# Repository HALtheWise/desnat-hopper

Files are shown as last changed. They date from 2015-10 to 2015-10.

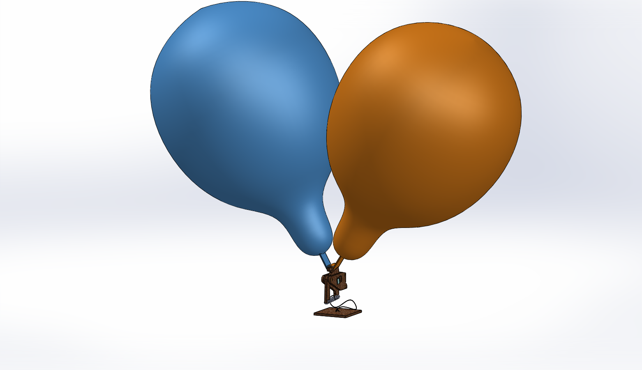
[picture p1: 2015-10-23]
Final cut files/Full blimp aslaunched 1.PNG

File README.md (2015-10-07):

# desnat-hopper
"Hopper" (blimp) for Design Nature

All first-year students at Olin get to take a class called Design Nature, 
in which we are challenged to create a biologically-inspired hopping creation from a very limited list of parts.

Project description (2015): http://web.archive.org/web/20151007031634/http://design.olin.edu/courses/dn/project/p1-requirements

Parts list (2015): http://web.archive.org/web/20151007031404/http://design.olin.edu/courses/dn/project/p1-prototyping-kit

Taking inspiration from nature, I noticed that the insects that reach the greatest heights and distances
do so by flying. A particulary enlightening example are spiders, some species of which can spin silk
balloons to loft themselves thousands of feet in the air and travel many miles.

Utilizing the presence of tap water in the list, and the general allowance on using tools to alter the given materials,
I have decided to split the H2O to make hydrogen, then use that to lift a blimp hundreds of feet in the air.

This is still a work in progress, and success is far from certain. This repository contains all the CAD 
and many of the calculations necessary to move forward.

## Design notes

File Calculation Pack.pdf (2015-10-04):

Eric Miller | Hoppers: Feasibility calculation pack | October 2, 2015

# Section 1: Buoyancy

## Starting point

- Dry mass of hopper is required to equal 50g or more, for this purpose hitting exactly 50g should be possible.
- Density of air at sea level is
- Density of 100% pure hydrogen is
- Density of 90% H2

, 10% O2

is
Assuming 90% effectiveness at separation during electrolysis:

= (http://www.wolframalpha.com/input/)

## Balloon volume

The party balloons we are given have a nominal diameter of 12”. Assuming spheres, their combined volume is thus:

=
Were this the case,

= 33.24 g

which is well shy of the needed lift.

Fortunately: inflating, measuring and photographing a balloon, then tracing in SolidWorks reveals:

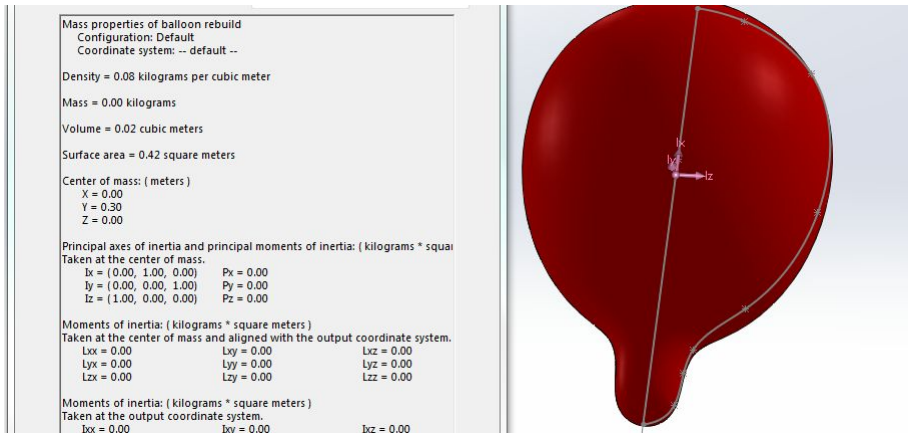
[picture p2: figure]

Volume of one balloon = 24607840.12 mm^3 = 0.024607840 m^3 Buoyancy of 2 balloons = 0.024607840 m^3 * 2 * 1.121 kilograms per cubic meter (http://www.wolframalpha.com/input/?i=0.024607840+m%5E3+*+2+*+1.121+kilograms+per+cubic+meter) = 55.17 grams

Note that it is probably possible to get significantly more volume inside by further overinflating if needed.

# Section 2: Aerodynamics

The obvious question is: how much vertical velocity does 5.17g of lift allow for? Note that this equates to about .05N of force.

## Solidworks flow simulation results (velocity = 0.5 m/s):

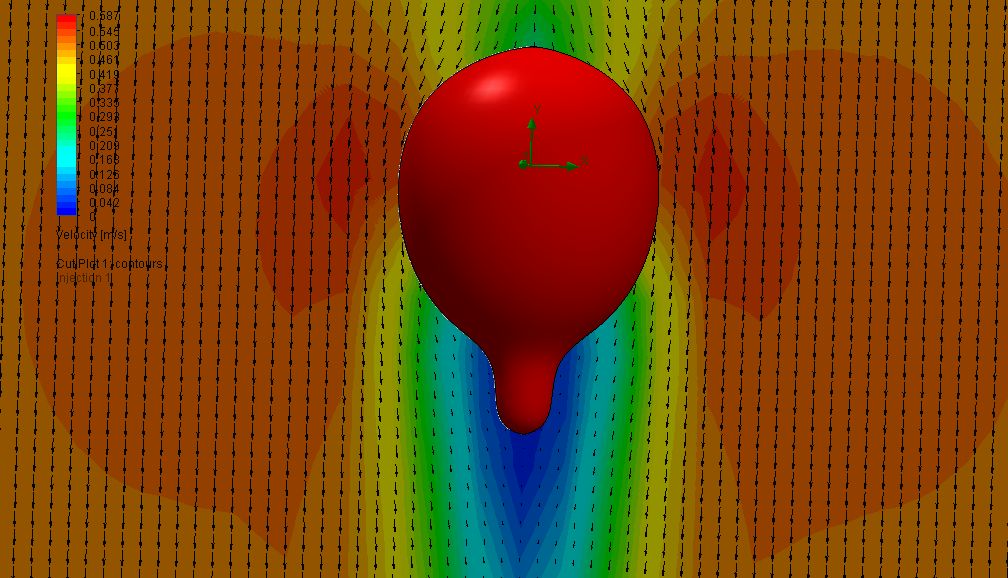
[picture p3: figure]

## Calculations

Because aerodynamic drag is roughly proportional to the square of velocity:

# Section 3: Ascent rate

As derived previously:

Thus

Because the target height of the device is 300ft, estimated travel time is

# Section 4: Comparison to simulation

The simulation data, pasted below, showed an estimated max height of 300 feet after 65 seconds of flight. The calculations here do not take into account gradual acceleration, and record more significant figures of accuracy, but are fundamentally based on the same aerodynamic calculations, and record a very similar height of 300 feet in 73.1 seconds. Stored mechanical energy is not particularly relevant to the calculations here, but there are other significant sources of error that make experimental testing necessary to figure out the correct timing to reach the height goal as accurately as possible. Firstly, the surface properties of the balloons aerodynamically are not necessarily modeled correctly, nor is the angle of attack modelled. Secondly the gondola itself has significant effect on the flight that is not properly accounted for in simulations or calculation. Overall, the damper effect used in the simulation matches expected results reasonably well.

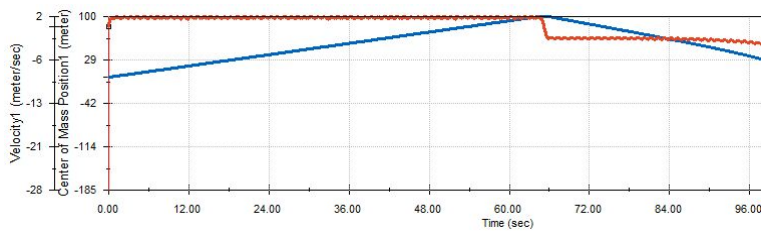
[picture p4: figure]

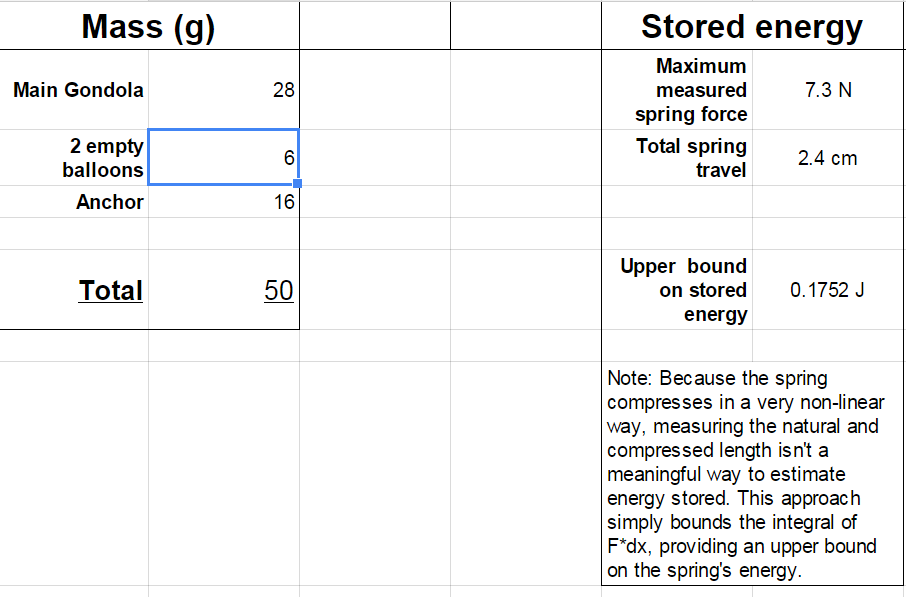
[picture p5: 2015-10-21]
Qualification calculations.PNG

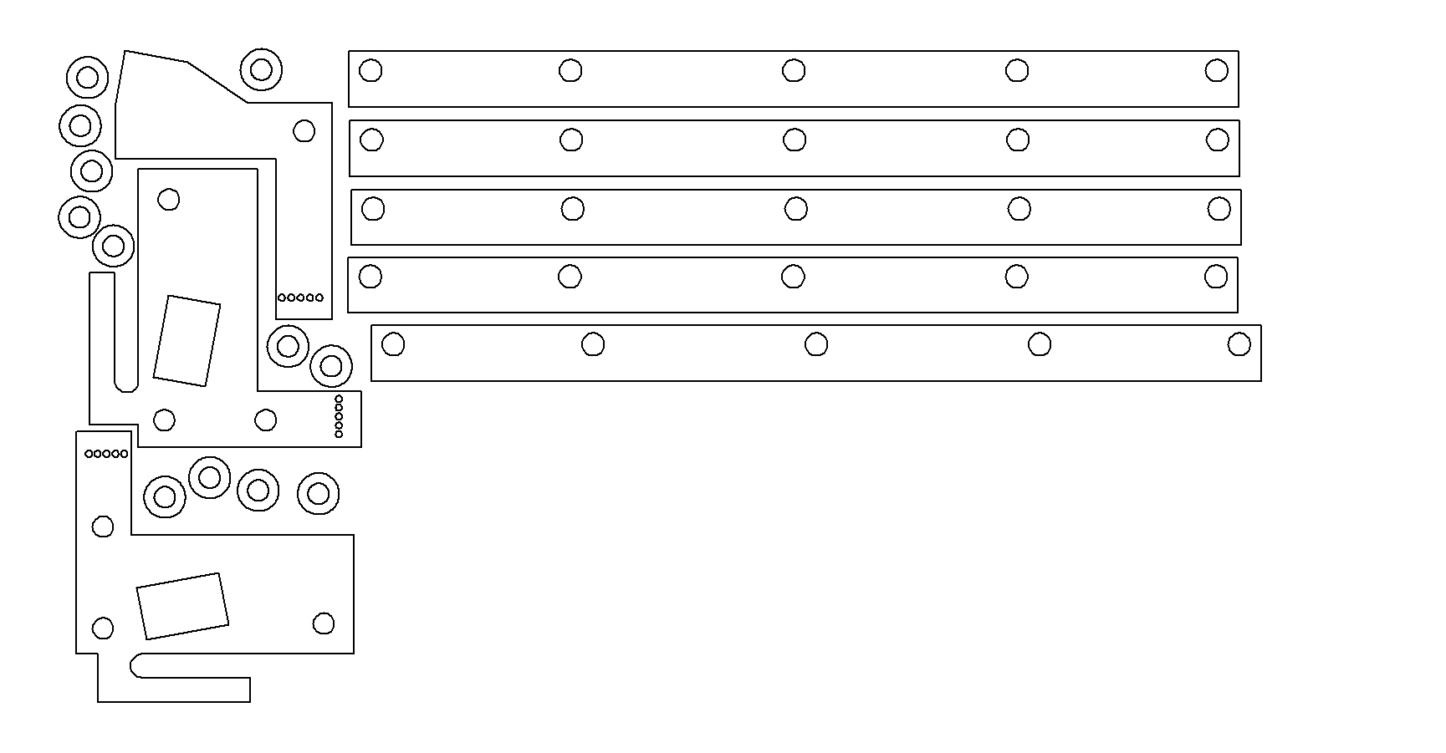
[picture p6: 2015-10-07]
Final cut files/Cutting files/EricMiller_cut_file.JPG

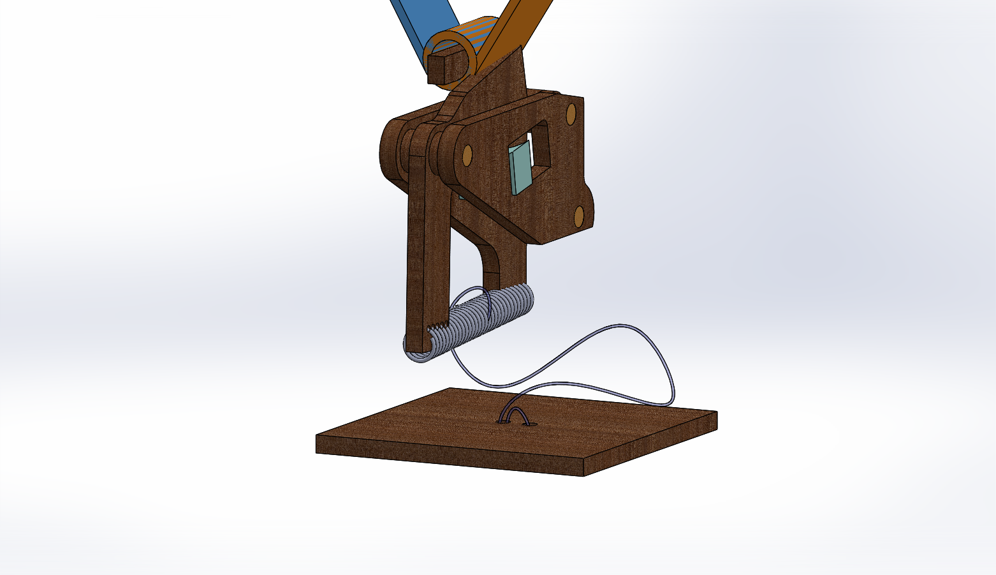
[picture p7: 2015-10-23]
Final cut files/Full blimp aslaunched 2.PNG

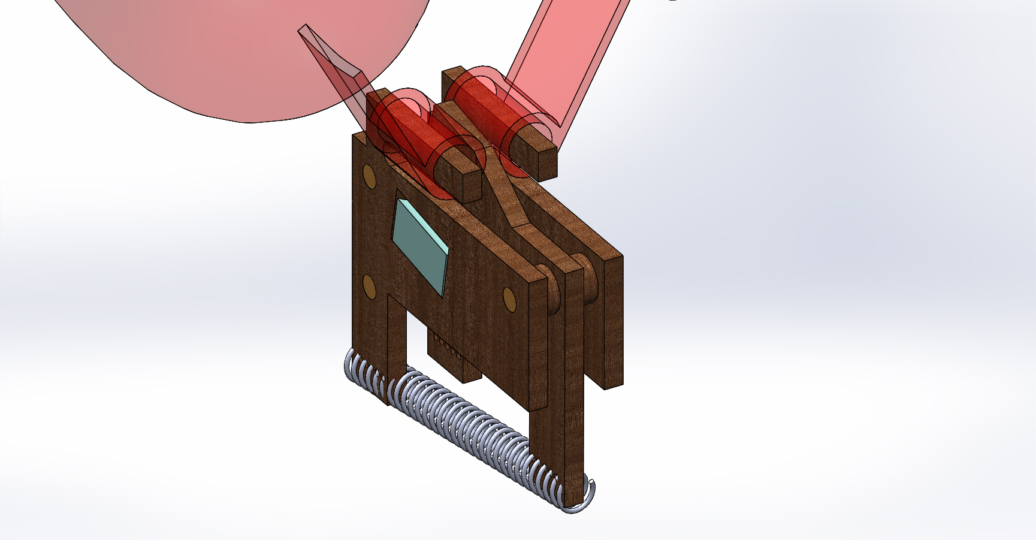
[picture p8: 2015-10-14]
Final cut files/Full blimp.JPG

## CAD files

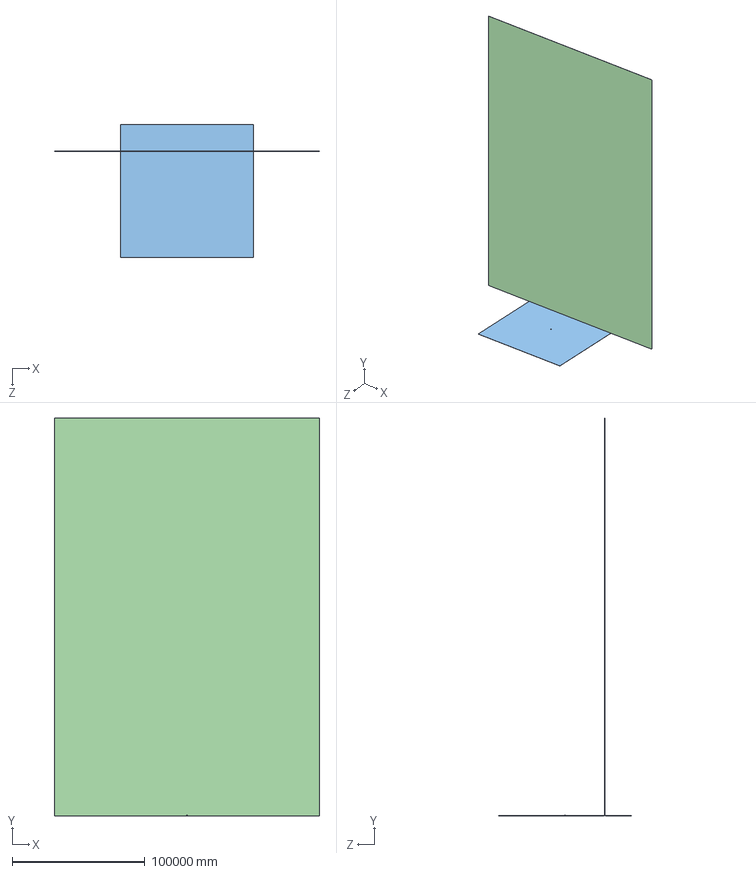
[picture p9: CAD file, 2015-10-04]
Dynamics Simulation/blimp.SLDASM
200000.0 x 300100.0 x 100000.0 mm
Gondola
balloon rebuild x 2
Ground^blimp
Sky^blimp

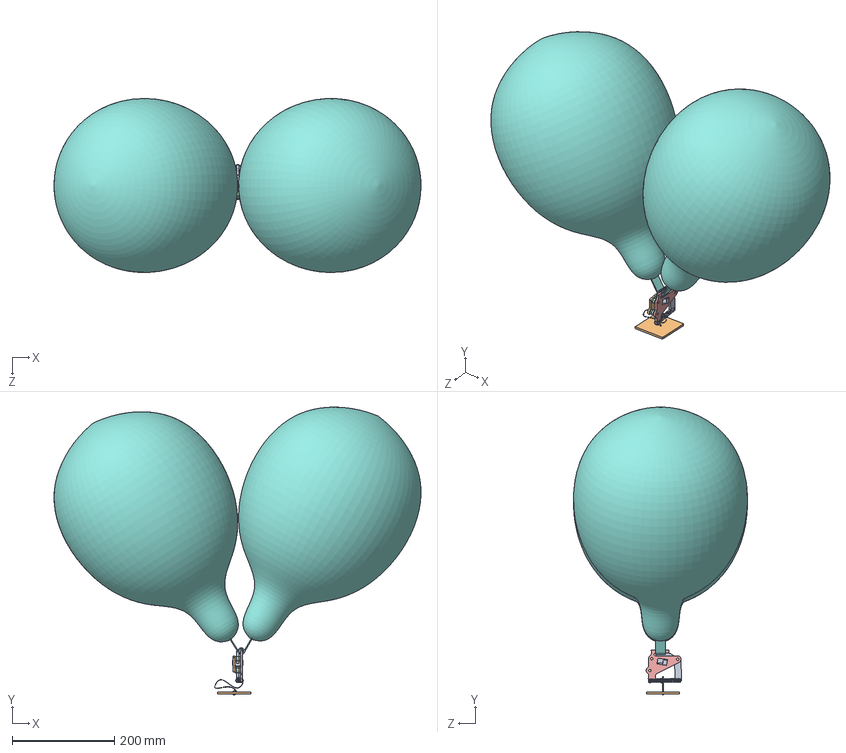
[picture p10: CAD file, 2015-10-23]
Final cut files/Full blimp.SLDASM
717.3 x 562.5 x 340.2 mm
Main rotating part
Butchered solid part
Basic spacer x 6
Fullwidth spacer x 2
Main solid part
spring-1986K860
Dowel^Full Gondola x 3
balloon rebuild x 2
Ice chunk
Anchor^Full blimp

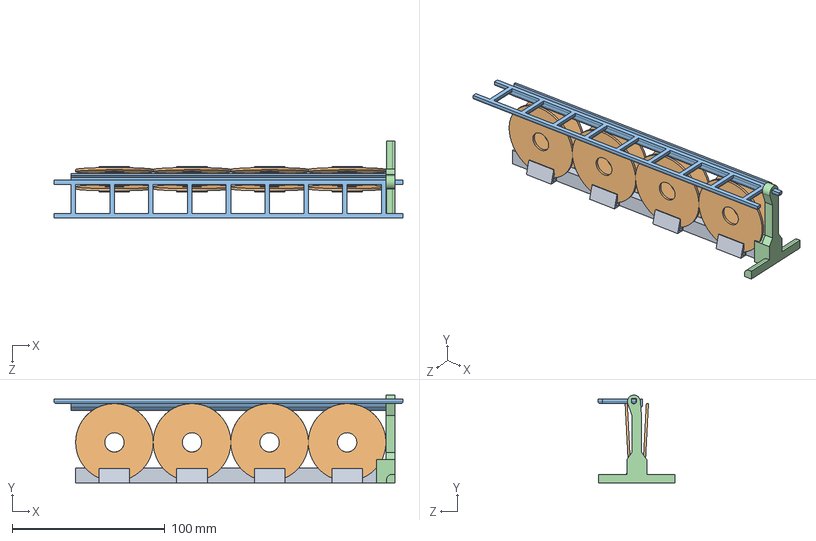
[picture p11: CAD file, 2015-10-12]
H2 factory/Prototype 3/Hydraulysis rig.SLDASM
228.6 x 57.6 x 50.4 mm
Electrode holder
large washer (stock) x 8
Collector
Vertical support

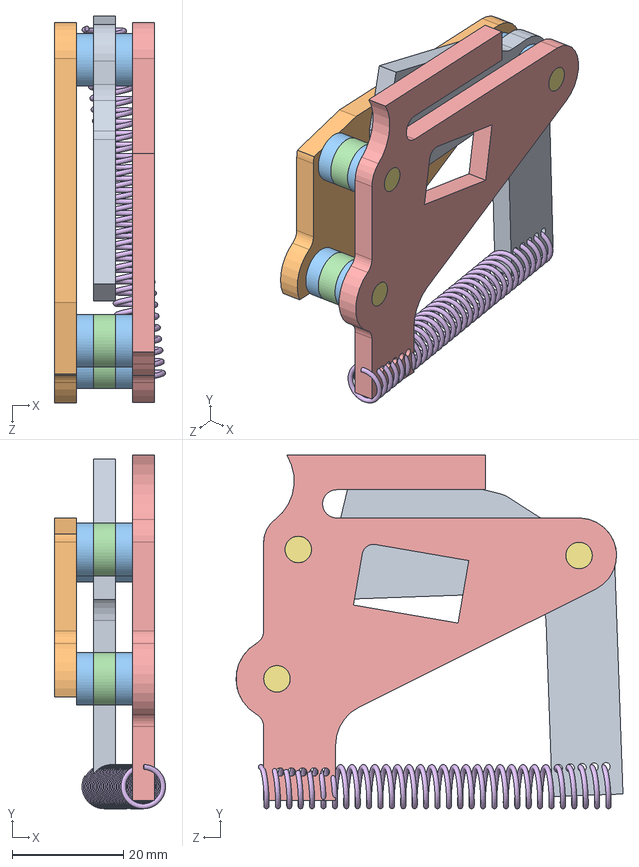
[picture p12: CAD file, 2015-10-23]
Final cut files/Full Gondola.SLDASM
19.9 x 63.5 x 69.5 mm
Main rotating part
Butchered solid part
Basic spacer x 6
Fullwidth spacer x 2
Main solid part
spring-1986K860
Dowel^Full Gondola x 3

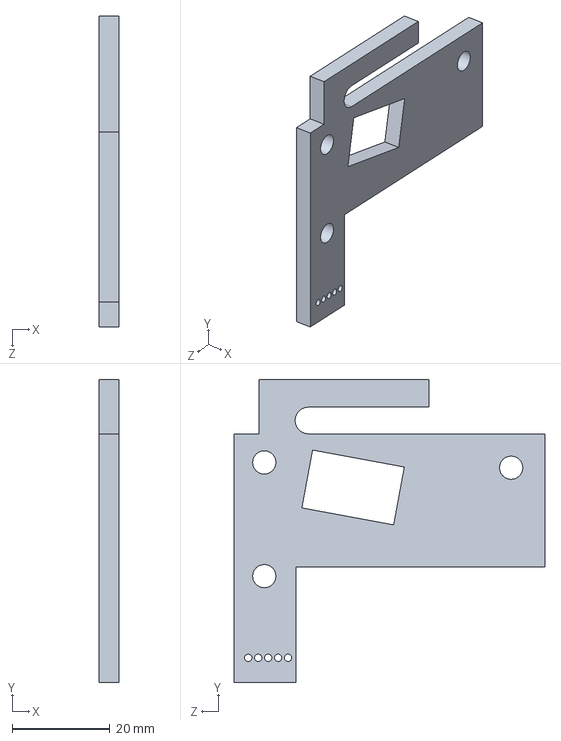
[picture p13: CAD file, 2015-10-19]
Final cut files/Main solid part.SLDPRT
4.00 x 61.9 x 63.5 mm

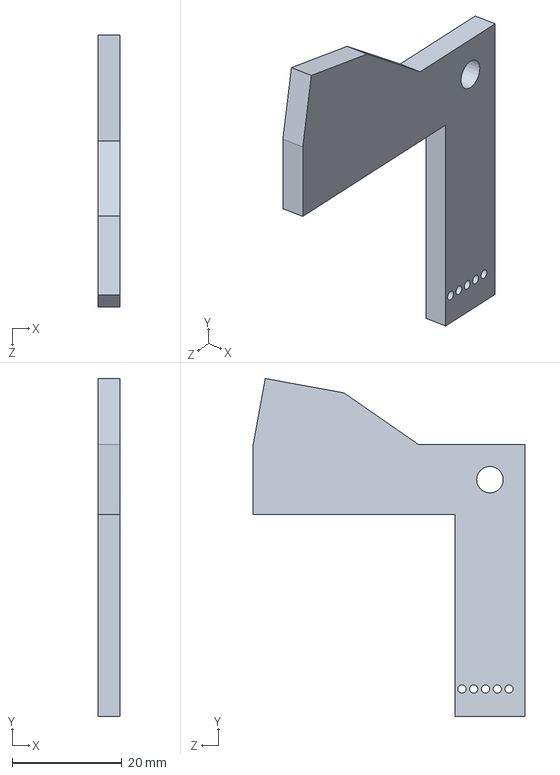
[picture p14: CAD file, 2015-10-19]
Final cut files/Main rotating part.SLDPRT
4.00 x 61.5 x 49.4 mm

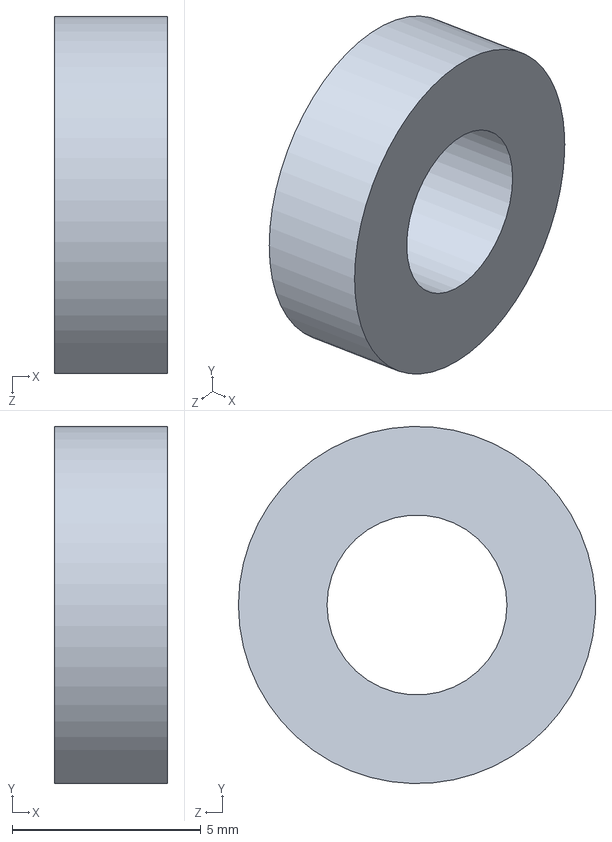
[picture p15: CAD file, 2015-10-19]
Final cut files/Fullwidth spacer.SLDPRT
3.00 x 9.45 x 9.45 mm

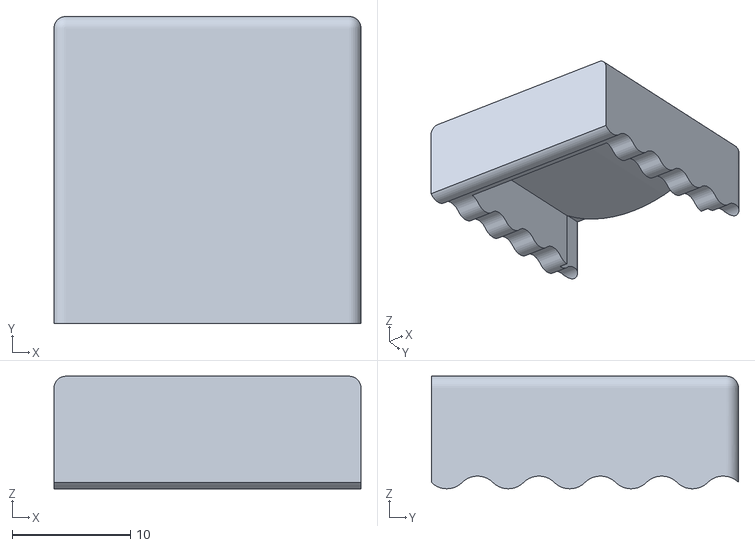
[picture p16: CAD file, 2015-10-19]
Final cut files/printing parts/Ice mold upper.STL
26.0 x 26.0 x 9.54

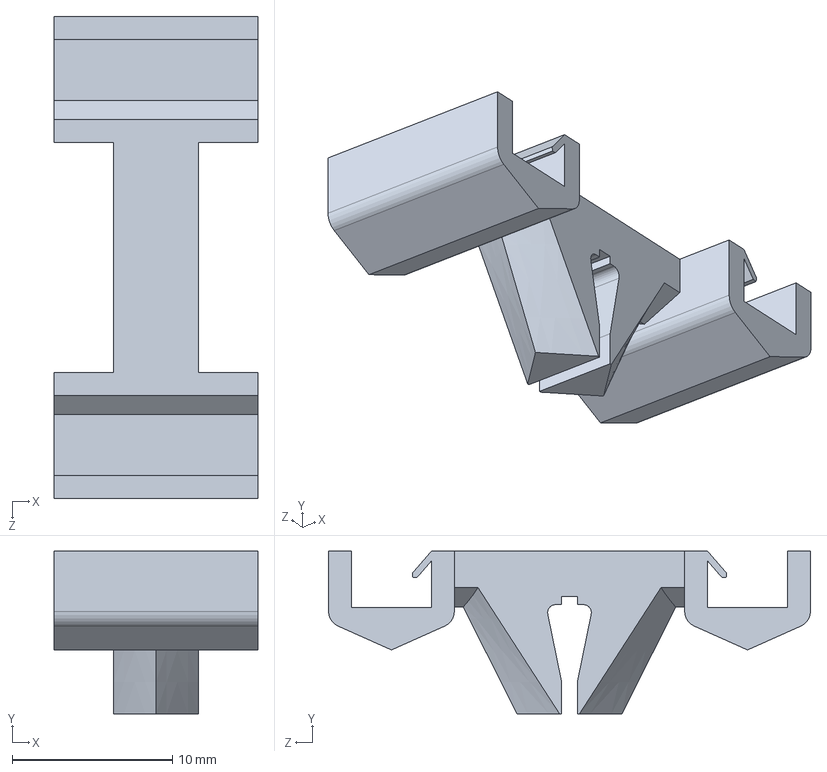
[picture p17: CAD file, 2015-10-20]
H2 factory/Must be final/Bubble divider.SLDPRT
12.7 x 10.2 x 30.0 mm

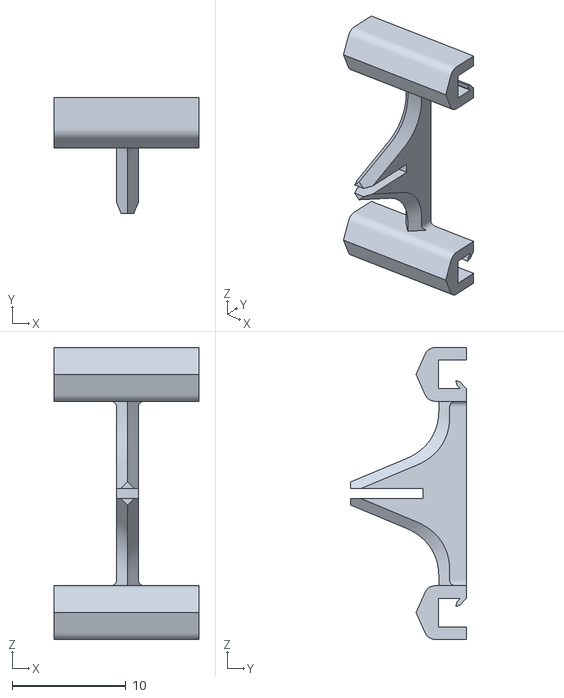
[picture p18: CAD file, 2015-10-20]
H2 factory/Must be final/printing/Bubble divider smooth.STL
12.7 x 10.2 x 25.7

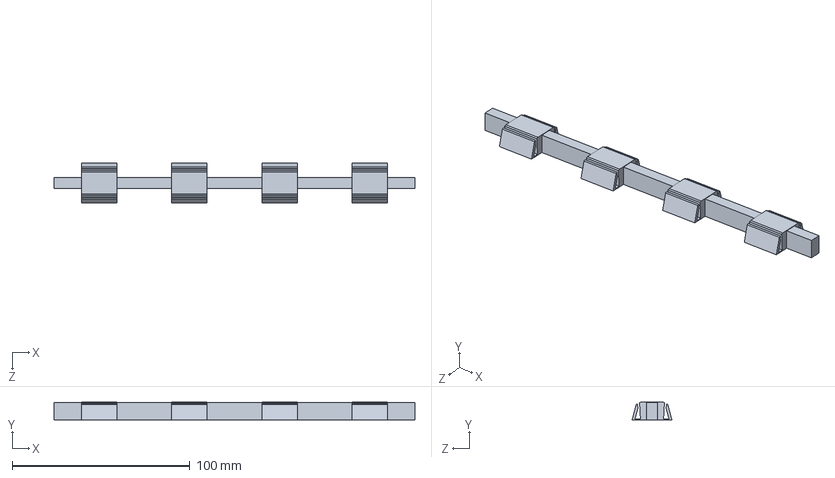
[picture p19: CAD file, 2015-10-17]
H2 factory/Prototype 3/Electrode holder.SLDPRT
203.2 x 10.1 x 22.5 mm

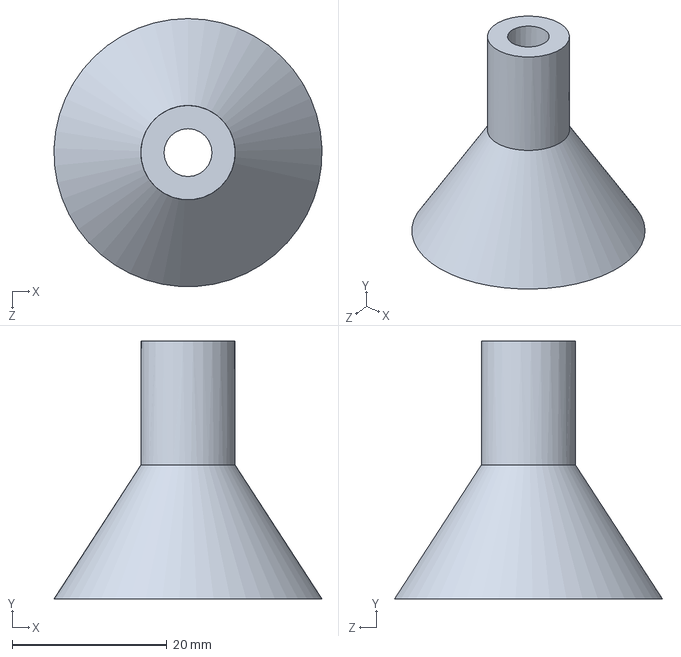
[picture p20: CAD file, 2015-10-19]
H2 factory/Transport/printing/small cone.SLDPRT
34.6 x 33.3 x 34.6 mm

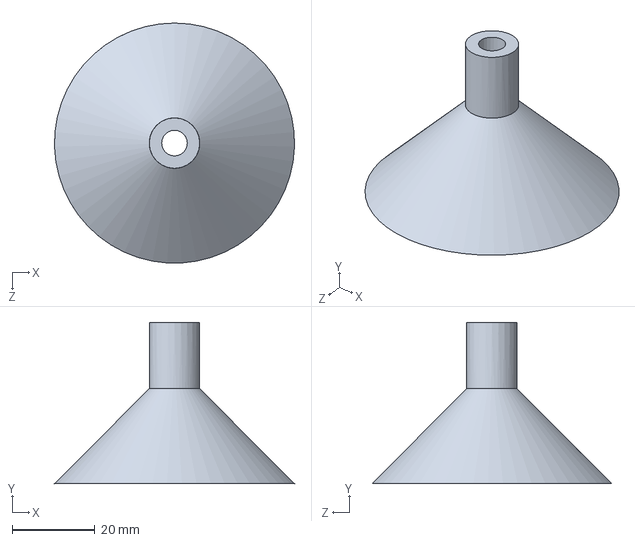
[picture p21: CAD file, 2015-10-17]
H2 factory/Transport/Rear Pump Adapter.SLDPRT
58.0 x 38.9 x 57.9 mm

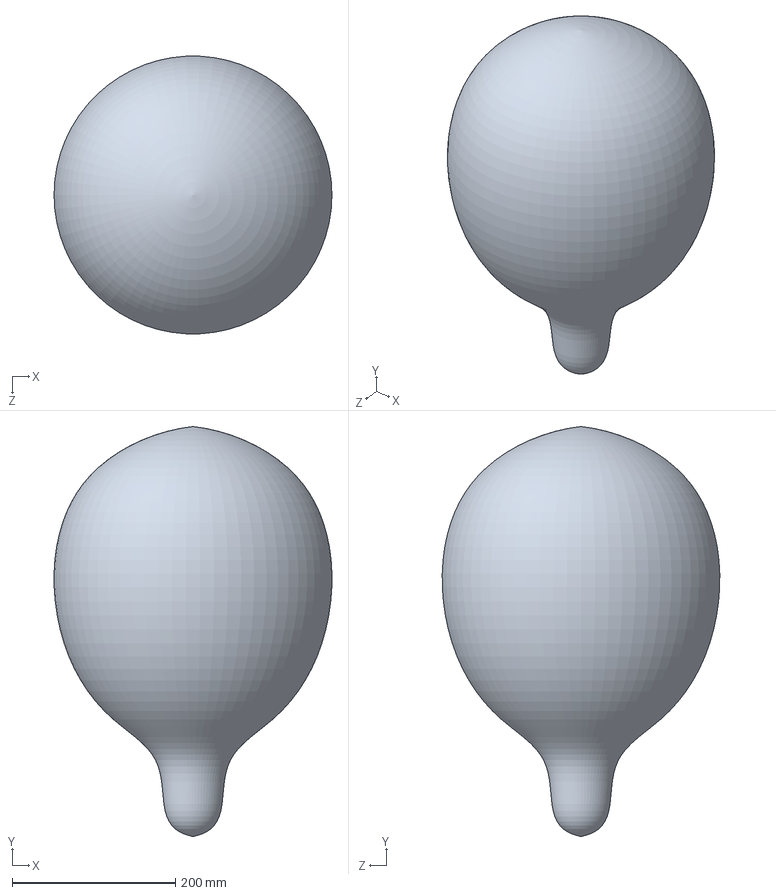
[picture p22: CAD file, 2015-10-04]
Dynamics Simulation/balloon.SLDPRT
340.1 x 501.7 x 339.6 mm

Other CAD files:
H2 factory/Prototype 3/print files/Electrode holder wide.STL
Final cut files/Ice chunk.SLDPRT
Final cut files/printing parts/Ice mold lower.STL
H2 factory/Must be final/Cross tube holder.SLDPRT
Dynamics Simulation/Gondola.SLDPRT
Dynamics Simulation/balloon-bkup.SLDPRT
Final cut files/Basic spacer.SLDPRT
Final cut files/Butchered solid part.SLDPRT
Final cut files/Cutting files/EricMiller cut file.slddrw
Final cut files/Ice mold.SLDPRT
Final cut files/balloon rebuild.SLDPRT
Final cut files/printing parts/Ice mold.STL
Final cut files/spring-1986K860.sldprt
H2 factory/Must be final/Bubble divider wide.SLDPRT
H2 factory/Must be final/Wire holder.SLDPRT
H2 factory/Must be final/clip.SLDPRT
H2 factory/Must be final/metal plate.SLDPRT
H2 factory/Must be final/printing/Bubble divider 3d.STL
H2 factory/Must be final/printing/Bubble divider inbetween.STL
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

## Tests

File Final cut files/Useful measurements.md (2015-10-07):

Wooden dowel:
-Nominal diameter: 3/16 in
-Free rotate diameter: 0.19 in

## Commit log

2015-10-03 initial commit
    Contains partially finished Dynamics simulation
    [Gondola.SLDPRT, balloon rebuild.SLDPRT, balloon-bkup.SLDPRT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]
2015-10-03 Added grass
    Basic simulation functional, but damping needed.
    [Gondola.SLDPRT, balloon rebuild.SLDPRT, blimp.SLDASM]
2015-10-03 Fixed blimp to ground
    [Gondola.SLDPRT, blimp.SLDASM]
2015-10-03 Added ground/sky for visual effect
    [Gondola.SLDPRT, balloon rebuild.SLDPRT, blimp.SLDASM]
2015-10-03 Added dampers to prevent ridiculousness
    [Gondola.SLDPRT, balloon rebuild.SLDPRT]
2015-10-03 Looks pretty nice
    Only problem is spring connecting balloons after popping
    [Gondola.SLDPRT, balloon rebuild.SLDPRT]
2015-10-03 Added spring mount component
    It needed mass, which is stupid.
    [balloon rebuild.SLDPRT]
2015-10-04 Almost working spring version
    Except for a crash error
2015-10-04 Same failing result, using a damper this time.
    [balloon rebuild.SLDPRT]
2015-10-04 Really nice looking sim
    Only remaining bug is late-stage acceleration
2015-10-04 Fixed angle issues
    Longer simulation would be nice.
    [balloon rebuild.SLDPRT]
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2015-10-04 Near-final model
    Hopefully no more changes
    [balloon rebuild.SLDPRT, blimp.SLDASM]
2015-10-05 Initial commit for EP1
    Contains only empty assembly
    [Full Blimp.SLDASM]
2015-10-05 Created floor
    Contains a few sketch guides
    [Gondola main floor.SLDPRT]
2015-10-05 Undimensione lever
    Started work on a parametric design for trigger lever
    [Trigger cam lever.SLDPRT]
2015-10-06 Sketchy prototype of washer holder
    [holder.SLDPRT, washer holder.STL]
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2015-10-07 Basic wooden frame component modelled
    [Frame piece.SLDPRT, large washer (stock).SLDPRT]
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2015-10-07 Modelled thin frame part (probably 3D printed)
    [Thin frame piece.SLDPRT]
2015-10-07 Slightly decreased thin piece thickness
    Intended to better match measured washer dimensions while ensuring tight
    pinch
    [Thin frame piece.SLDPRT]
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2015-10-07 Mirrored to other electrode
    [laser cut electrode frame.SLDASM]
2015-10-07 Finished mirroring and assembling basic (tight) electrode frame
    [laser cut electrode frame.SLDASM]
2015-10-07 Lifted washers out slightly
    [Thin frame piece.SLDPRT, laser cut electrode frame.SLDASM]
2015-10-07 Misc renames and stuff
    [3D printed holder.SLDPRT, Thick frame piece.SLDPRT]
2015-10-07 Fresh start with experimental prototype #1
    [Gondola main floor.SLDPRT, Trigger cam lever.SLDPRT]
2015-10-07 Basic sketch of rotating part completed with spring mount holes
    [Main rotating part.SLDPRT]
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2015-10-07 Basic sketch of main solid part
    Contains ice cube holder and spring mount
    [Main solid part.SLDPRT]
2015-10-07 Normalized dimensions
    Also added extra support posts
    [Main rotating part.SLDPRT, Main solid part.SLDPRT]
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2015-10-07 Fixed folder organization mistake
    [Main solid part.SLDPRT]
2015-10-07 Basic assembley completed, balloon hook added
    I wasn't very good about frequent commits, was I?
    [Basic spacer.SLDPRT, Full Blimp.SLDASM, Full Gondola.SLDASM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]
2015-10-07 Exported thin frame piece for printing
    [Thin frame piece.STL]
2015-10-07 Changed material of fixed part to hardboard
    [Full Gondola.SLDASM, Main solid part.SLDPRT]
2015-10-07 Copied files in preparation for cut file generation
    [Basic spacer.SLDPRT, Main rotating part.SLDPRT, Main solid part.SLDPRT]
2015-10-07 Created cut file for parts
    [EricMiller cut file.slddrw]
2015-10-07 Mirrored second copy of fixed part
    [EricMiller cut file.slddrw]
2015-10-07 Final submitted laser cutting file
    [EricMiller cut file.slddrw]
2015-10-07 Added 5x frame pieces to cut file
    [EricMiller cut file.slddrw, Thick frame piece.SLDPRT]
2015-10-07 Added gitignore line for group assembley work
    [EricMiller cut file.slddrw]
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2015-10-08 Added spring to assembly
    [Main solid part.SLDPRT]
2015-10-10 More work on cleaning up solid mode
    [Main solid part.SLDPRT]
2015-10-10 Started design of H2 factory #3
    [Washer clip.SLDPRT]
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2015-10-10 Exported wide and narrow versions
    [Washer clip narrow.STL, Washer clip wide.STL]
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2015-10-10 Made clip tall again
    [Washer clip.SLDPRT]
2015-10-10 Moved testing stuff to separate folder
    [Electrolyis rig #3.SLDPRT, Washer clip narrow.STL, Washer clip tall.STL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]
2015-10-10 Increased wire cutout size to 0.3mm
    [Electrolyis rig #3.SLDPRT]
2015-10-10 Mirrored slits and connected
    [Electrolyis rig #3.SLDPRT]
2015-10-10 Split lines for better extrusion options
    [Electrolyis rig #3.SLDPRT]
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2015-10-10 Created clip in proper place
    [Electrolyis rig #3.SLDPRT]
2015-10-10 Successfully duplicated to 8 clips
    [Electrolyis rig #3.SLDPRT]
2015-10-12 Updated to repair massive damage from Google Drive sync. Only changes are exports of printing files. Important note: the ladder.x3g file prints at 210C to be compatible with clear filament.
    [Electrolyis rig #3.STL, Tube spreader.SLDPRT, Tube spreader.STL]
2015-10-12 Renamed files for convenience in assembly
    [Collector.SLDPRT, Electrode holder.SLDPRT, Hydraulysis rig.SLDASM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]
2015-10-12 Initial assembly of disks and holder and collector
    [Hydraulysis rig.SLDASM]
2015-10-12 Finished basic sketch of vertical support
    [Electrode holder.SLDPRT, Hydraulysis rig.SLDASM, Vertical support.SLDPRT]
2015-10-12 Added more division lines
    [Vertical support.SLDPRT]
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2015-10-12 Outset hole for roof mount
    [Vertical support.SLDPRT]
2015-10-12 Added foot to support
    [Vertical support.SLDPRT]
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2015-10-14 Shortened spring
    [Full Gondola.SLDASM, spring-1986K860.sldprt]
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2015-10-14 Ran interference detection
    [Full blimp.SLDASM]
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2015-10-15 Sliced hose plug to try to induce strong layer in middle
    [Hose plug.SLDPRT, Hose plug.STL]
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2015-10-15 Completed rough model of back adapter for pump
    [Rear Pump Adapter.SLDPRT]
2015-10-17 Printed out cones for transport; Started work on final version of H2 factory
    [Electrode holder wide.STL, Electrode holder.SLDPRT, Full blimp.SLDASM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]
2015-10-19 Began work on final cut files for gondola Signed-off-by: Eric Miller <eric@legoaces.org>
    [Basic spacer.SLDPRT, EricMiller cut file.slddrw, Full Gondola.SLDASM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]
2015-10-19 Narrowed interior gap to mesh with test results
    [Basic spacer.SLDPRT, Full Gondola.SLDASM, Fullwidth spacer.SLDPRT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]
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2015-10-19 Completely refactored bubble separator to be small single rung
    [Bubble divider 3d.SLDPRT]
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2015-10-19 Made two different size dividers for test printing
    [Bubble divider inbetween.SLDPRT, Bubble divider inbetween.STL, Bubble divider wide.SLDPRT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]
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2015-10-20 Fixed clip attachment direction and added amazing fillets
    [Bubble divider wide.SLDPRT]
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2015-10-20 Reshaped groove to decrease strain and prevent snapping
    [Bubble divider.SLDPRT]
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2015-10-20 Massively strengthened bubble divider through bulk
    [Bubble divider.SLDPRT, Bubble divider.STL]
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
